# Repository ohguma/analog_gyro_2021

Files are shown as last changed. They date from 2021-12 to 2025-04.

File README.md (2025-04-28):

# アナログ出力ジャイロセンサ

+ 電源が5Vのマイコンキットなどのアナログ入力で利用するためのジャイロセンサ。
+ Arduino 互換機として作成。

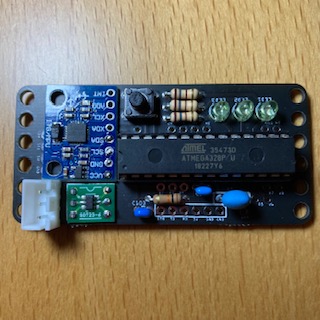
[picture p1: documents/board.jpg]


## スケッチについて

+ こちらで紹介されている「センサーから値を取得するプログラム」と「センサーのキャリブレーションについて」のスケッチ（※1）をまとめて、スイッチの長押しロジックとDAC出力機能を追加して作成。
  + [センサーの使い方(ジャイロ編) : Revolution_Include](http://blog.livedoor.jp/revolution_include/archives/2815979.html)
+ 事前にgithubの「jrowberg/i2cdevlib」をダウンロードしておく。
  + https://github.com/jrowberg/i2cdevlib
  + 「code」ボタンの「Download ZIP」からダウンロードする。
  + 「i2cdevlib-master.zip」を展開し、「Arduino」フォルダ内にある「I2Cdev」「MPU6050」の2フォルダを「Arduino IDE」のライブラリフォルダ内にコピーする。
  + Arduino IDEを再起動し、メニューの「スケッチ」→「ライブラリのインクルード」に「I2Cdev」「MPU6050」があることを確認する。
+ ※1の2つのスケッチではどちらもMPU6050というデータ型が利用されているが、 「MPU6050_6Axis_MotionApps20.h」と「MPU6050.h」をそのまま同時にインクルードするとデータ型「MPU6050」の2重定義でコンパイルがエラーになるので、「#define I2CDEVLIB_MPU6050_TYPEDEF」を事前に記述して「MPU6050.h」でのデータ型「MPU6050」の定義を回避しつつ、自作スケッチではデータ型「MPU6050」でなく、それぞれのヘッダーファイルで定義されている元の形「MPU6050_6Axis_MotionApps20」「MPU6050_Base」を利用した。
+ 起動時の方向を基準として動作する。基準向きの場合に2.5Vを出力し、それより右に向くと電圧が下がり（最小0V）、左に向くと電圧が上がる（最大5V）。基準向きの反対方向で0Vと5Vが入れ替わる。
+ 基準向きから+-1度の範囲内で中央のLEDが点灯する。基準向きから+-5度の範囲内で左右のLEDが点灯する。それ以外の向きはLEDは消灯する。
+ タクトスイッチを短押しした時の方向を基準方向としてリセットする。3秒以上長押しするとキャリブレーションを開始する。キャリブレーション時はセンサーは静止した状態にしておき、LEDが3つとも点灯したらスイッチを離し、キャリブレーションの終了を待つ（数十秒）。 
+ キャリブレーション時に取得したジャイロセンサのオフセット値はEEPROMに保存する。起動時にはEEPROMからオフセット値を読み込んで動作するため、最初にスケッチをアップロードした際にはすぐにキャリブレーションする。

## パーツリスト
個数は明記なければ1個。
+ [Ａｒｄｕｉｎｏ　Ｂｏｏｔｌｏａｄｅｒ書込済（５Ｖ　１６ＭＨｚ仕様）　ＡＴｍｅｇａ３２８Ｐ](https://akizukidenshi.com/catalog/g/gI-12774/)
  + 自前でブートローダーが書き込めるなら「 [ＡＶＲマイコン　ＡＴＭＥＧＡ３２８Ｐ－ＰＵ](https://akizukidenshi.com/catalog/g/gI-03142/)」もあり。
+ MPU6050
  + amazon などでMPU6050(GY-521)として売られているもの。数百円。 
+ [ＭＣＰ４７２６搭載１２ビットＤ／Ａ変換モジュール](https://akizukidenshi.com/catalog/g/gK-07995/)
  + 本センサは水平に設置する前提でヨー軸角度をアナログ出力するのでそのためのDAC。
+ [セラミック発振子（セラロック）コンデンサー内蔵タイプ　１６ＭＨｚ](https://akizukidenshi.com/catalog/g/gP-09576/)
+ 28ピン　ICソケット
+ タクトスイッチ
+ 3mmLED 3個
+ LED用電流制限抵抗 3個（150～1KΩ程度）
+ 328Pリセット回路用の抵抗10KΩ、セラミックコンデンサ 0.01μF(10nF) 103
+ セラミックコンデンサ 0.1μF(100nF) 104　328P用パスコン
+ 配線用のコネクタなど

## 基板・回路図

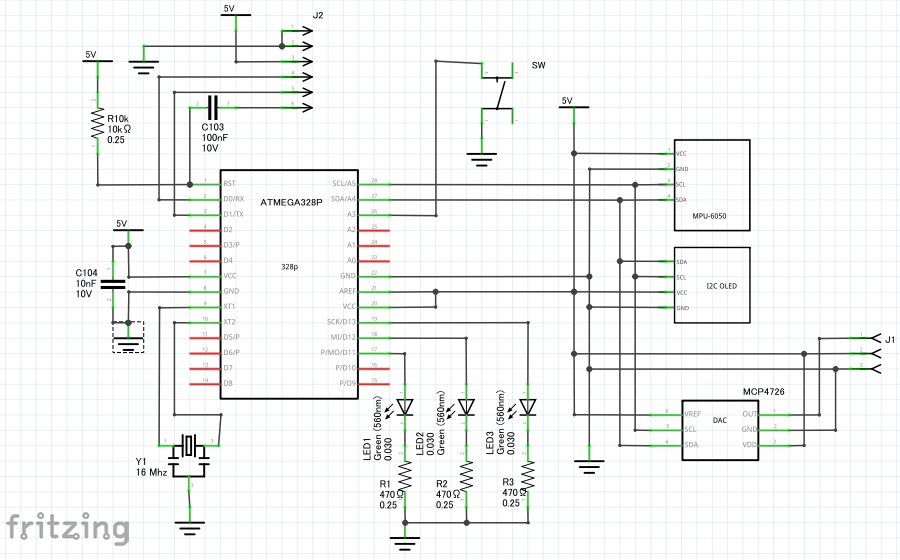
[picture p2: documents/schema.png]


+ OLEDはコストカットのため未実装。なお、I2C接続で画素数128x32のものを直接基板に取り付けできる予定だったが、MPU6050の基板が邪魔になっている。
+ [Fritzing](https://fritzing.org/)で設計し、基板作成まで行った。
+ 基板作成の面付けについては 「[Fritzing入門実習テキスト「Fritzing Basics」#マッハ新書 （ダウンロード商品）](https://booth.pm/ja/items/1414214)」の手順に従った。
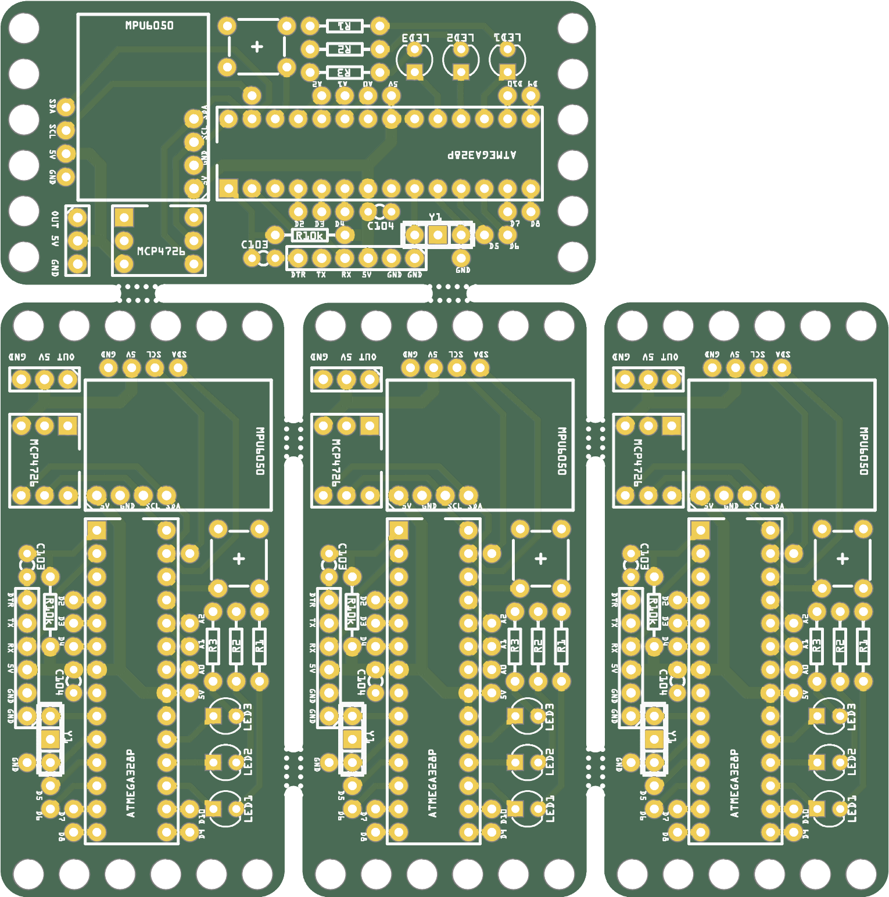
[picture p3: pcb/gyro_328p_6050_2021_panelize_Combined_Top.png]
  + 
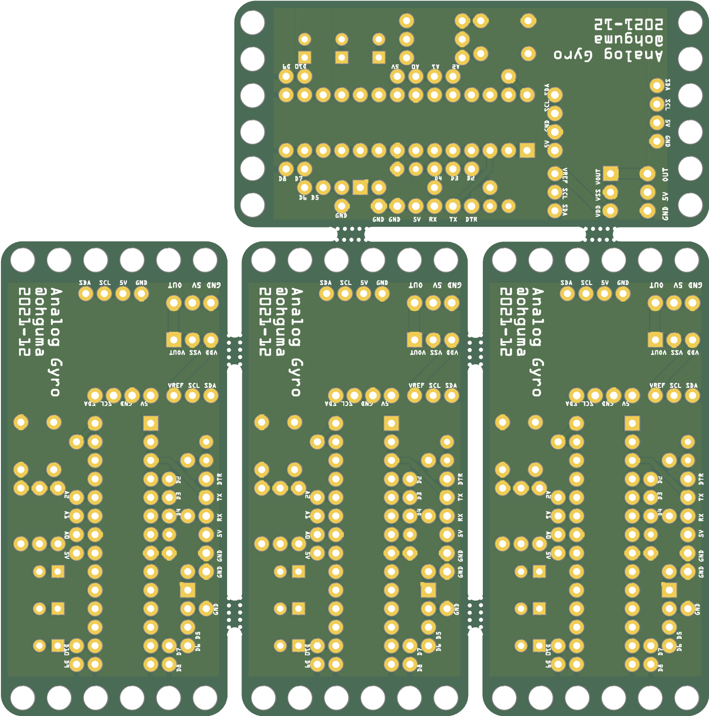
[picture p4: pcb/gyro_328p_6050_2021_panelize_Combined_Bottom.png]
  + 
+ 基板作成は「[JLCPCB](https://jlcpcb.com/)」。つや消し黒が安い。発注から1週間ほどで到着（運送便はUPS、支払いはpaypal）。
  + twitter https://twitter.com/JLCPCB_Japan
+ [発注時ガーバーファイル](./pcb/combined.zip)
+ [GerberPanelizer.exeデータ](./pcb/gyro_328p_6050_2021_panelize.gerberset)
+ [Frizingのプリント基板外形SVG](./pcb/gyro_328p_6050_2021.svg)

+ [KiCAD8データ](./pcb/analog_gyro_2021.zip)

----
2021-12-29 ohguma

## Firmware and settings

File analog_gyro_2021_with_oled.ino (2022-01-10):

/**
  Analog出力ジャイロ with OLED
  2021-12-29 by ohguma

  ▼パーツ
  DAC          MCP4726 秋月
  ジャイロセンサ MPU6050 Amazonなど

  ▼ピン設定
  入力
  　基準向きリセットSW   A3
  出力
  　向き表示LED1,2,3    D11,D12,D13

  ▼参考
  センサーの使い方(ジャイロ編)
  http://blog.livedoor.jp/revolution_include/archives/2815979.html
*/

//#define DEBUG

#ifdef DEBUG
#define DEBUG_PRINTLN(x) Serial.println(x)
#define DEBUG_PRINT(x) Serial.print(x)
#else
#define DEBUG_PRINTLN(x)
#define DEBUG_PRINT(x)
#endif

#include <EEPROM.h>
#include <Wire.h>
#include <I2Cdev.h>
//MP6050の重複をさける
#define I2CDEVLIB_MPU6050_TYPEDEF
#include <MPU6050.h>
#include <MPU6050_6Axis_MotionApps20.h>

//DACアドレス
#define MCP4726_ADDR 0x60

//OLED
//Adafruit_SSD1306の例「ssd1306_128x32_i2c」を流用
#include <SPI.h>
#include <Adafruit_GFX.h>
#include <Adafruit_SSD1306.h>
#define SCREEN_WIDTH 128 // OLED display width, in pixels
#define SCREEN_HEIGHT 32 // OLED display height, in pixels
// Declaration for an SSD1306 display connected to I2C (SDA, SCL pins)
#define OLED_RESET     4 // Reset pin # (or -1 if sharing Arduino reset pin)
Adafruit_SSD1306 display(SCREEN_WIDTH, SCREEN_HEIGHT, &Wire, OLED_RESET);
int c = 0;

//PIN設定
#define LED_RIGHT 13
#define LED_CENTER 12
#define LED_LEFT 11
#define PIN_SW A3
////PIN設定（旧基盤）
//#define LED_RIGHT 11
//#define LED_CENTER 10
//#define LED_LEFT 9
//#define PIN_SW 12

//方向リセットを始めるスイッチ長押し時間[ms]
#define MS_RESET 50
//キャリブレーションを始めるスイッチ長押し時間[ms]
#define MS_CALIB 3000

//キャリブレーション時のオフセット値を保存するEEPROMアドレス
#define POS_GYRO_X  0x00
#define POS_GYRO_Y  0x02
#define POS_GYRO_Z  0x04
#define POS_ACCEL_Z 0x06

//長押し用タイマー変数。押された瞬間のmillis()を保存する
unsigned long tm_reset = 0;
unsigned long tm_calib = 0;

//DAC出力するローカル角度
int16_t mydeg = 0;
//ジャイロセンサ角度とローカル角度のオフセット
int16_t myinitdeg = 0;

//ジャイロセンサ角度計算用
MPU6050_6Axis_MotionApps20 mpu;
int16_t gyro = 0;             //ジャイロセンサ角度
static uint8_t mpuIntStatus;
static bool dmpReady = false; // set true if DMP init was successful
static uint16_t packetSize;   // expected DMP packet size (default is 42 bytes)
uint16_t fifoCount;
uint8_t fifoBuffer[64]; // FIFO storage buffer                 // orientation/motion vars
Quaternion q;           // [w, x, y, z]         quaternion container
VectorFloat gravity;    // [x, y, z]            gravity vector
float ypr[3];           // [yaw, pitch, roll]   yaw/pitch/roll container and gravity vector

void setup()
{
  Serial.begin(9600);
  DEBUG_PRINTLN("Analog Gyro 2021-12");
  DEBUG_PRINTLN("Initialize...");
  //OLED
  if (!display.begin(SSD1306_SWITCHCAPVCC, 0x3C)) { // Address 0x3C for 128x32
    Serial.println(F("SSD1306 FAILED"));
    for (;;); // Don't proceed, loop forever
  }
  delay(1000);
  display.clearDisplay();
  display.setTextColor(WHITE);
  display.setTextSize(2);
  display.setCursor(0, 0);
  display.println(F("AnalogGyro"));
  display.setTextSize(1);
  display.setCursor(0, 16);
  display.println(F("2021-12 ohguma"));
  display.display();
  //ピン設定
  pinMode(LED_RIGHT, OUTPUT);
  pinMode(LED_CENTER, OUTPUT);
  pinMode(LED_LEFT, OUTPUT);
  pinMode(PIN_SW, INPUT_PULLUP);
  //出力初期化
  digitalWrite(LED_RIGHT, LOW);
  digitalWrite(LED_CENTER, LOW);
  digitalWrite(LED_LEFT, LOW);
  //ジャイロセンサ初期化
  init_gyro();
  attach_offset();
  DEBUG_PRINTLN("Start...");
}

void loop()
{
  if (digitalRead(PIN_SW) == HIGH) {
    //キーが押されていないデフォルト状態
    tm_reset = 0;
    tm_calib = 0;
    //ジャイロ値更新
    set_gyro_value();
    //ローカル角度に変換（-180< x <= 180）
    mydeg = gyro - myinitdeg;
    if (mydeg < -180) {
      mydeg += 360;
    } else if (mydeg > 180) {
      mydeg -= 360;
    }
    DEBUG_PRINTLN(mydeg);
    //DAC出力 -180～180のデータを0～4095(2^12-1)のデータに換算する
    int val = constrain(map(mydeg, -180, 180, 4095, 0), 0, 4095);
    Wire.beginTransmission(MCP4726_ADDR);
    Wire.write((uint8_t) ((val >> 8) & 0x0F));   // MSB: (D11, D10, D9, D8)
    Wire.write((uint8_t) (val));  // LSB: (D7, D6, D5, D4, D3, D2, D1, D0)
    Wire.endTransmission();
    //状態LED出力
    if (mydeg >= -5 && mydeg < -1 ) {
      digitalWrite(LED_LEFT, HIGH);
    } else {
      digitalWrite(LED_LEFT, LOW);
    }
    if (mydeg >= -1 && mydeg <= 1 ) {
      digitalWrite(LED_CENTER, HIGH);
    } else {
      digitalWrite(LED_CENTER, LOW);
    }
    if (mydeg > 1 && mydeg <= 5 ) {
      digitalWrite(LED_RIGHT, HIGH);
    } else {
      digitalWrite(LED_RIGHT, LOW);
    }
    if (c % 10 == 0) {
      draw_triangle(mydeg);
    }
    c++;
  } else if (tm_reset == 0 && tm_calib == 0) {
    //スイッチ押し時間計測開始
    tm_reset = millis();
    tm_calib = millis();
  } else if (tm_reset > 0 && millis() - tm_reset > MS_RESET) {
    //ローカル角度のリセット（現時点の向きを基準向きとする）
    tm_reset = 0;
    attach_offset();

  } else if (tm_calib > 0 && millis() - tm_calib > MS_CALIB) {
    //キャリブレーション開始
    tm_calib = 0;
    digitalWrite(LED_RIGHT, HIGH);
    digitalWrite(LED_CENTER, HIGH);
    digitalWrite(LED_LEFT, HIGH);
    action_calibration();
    digitalWrite(LED_RIGHT, LOW);
    digitalWrite(LED_CENTER, LOW);
    digitalWrite(LED_LEFT, LOW);
    init_gyro();
    attach_offset();
  }
}

//ローカル角度のリセット用のオフセット更新
void attach_offset()
{
  myinitdeg = gyro;
}

//ジャイロセンサ値の更新
void set_gyro_value()
{
  mpuIntStatus = false;
  mpuIntStatus = mpu.getIntStatus();
  fifoCount = mpu.getFIFOCount();
  if ((mpuIntStatus & 0x10) || fifoCount == 1024) {
    mpu.resetFIFO();
  } else if (mpuIntStatus & 0x02) {
    while (fifoCount < packetSize) {
      fifoCount = mpu.getFIFOCount();
    }
    mpu.getFIFOBytes(fifoBuffer, packetSize);
    fifoCount -= packetSize;
    mpu.dmpGetQuaternion(&q, fifoBuffer);
    mpu.dmpGetGravity(&gravity, &q);
    mpu.dmpGetYawPitchRoll(ypr, &q, &gravity);
    gyro = degrees(ypr[0]) + 180;
    if (gyro < 0) {
      gyro += 360;
    }
    if (gyro > 359) {
      gyro -= 360;
    }
  }
}

//ジャイロセンサ初期化
void init_gyro()
{
  int val;
  mpu.initialize();
  while (!mpu.testConnection()) {
  }
  if (mpu.testConnection() != true) {
    DEBUG_PRINTLN("MPU disconection");
    while (true) {}
  }
  if (mpu.dmpInitialize() != 0) {
    DEBUG_PRINTLN("MPU break");
    while (true) {}
  }
  EEPROM.get(POS_GYRO_X, val);
  mpu.setXGyroOffset(val);
  EEPROM.get(POS_GYRO_Y, val);
  mpu.setYGyroOffset(val);
  EEPROM.get(POS_GYRO_Z, val);
  mpu.setZGyroOffset(val);
  EEPROM.get(POS_ACCEL_Z, val);
  mpu.setZAccelOffset(val);
  mpu.setDMPEnabled(true);
  mpuIntStatus = mpu.getIntStatus();
  dmpReady = true;
  packetSize = mpu.dmpGetFIFOPacketSize();
  //少し待つ
  for (int i = 0; i < 100; i++) {
    set_gyro_value();
  }
}


// 以下は長押し時のキャリブレーション用
MPU6050_Base accelgyro;
int state = 0;
int16_t ax, ay, az, gx, gy, gz;
int mean_ax, mean_ay, mean_az, mean_gx, mean_gy, mean_gz;
int ax_offset, ay_offset, az_offset, gx_offset, gy_offset, gz_offset;
int buffersize = 1000;   //Amount of readings used to average, make it higher to get more precision but sketch will be slower  (default:1000)
int acel_deadzone = 8;   //Acelerometer error allowed, make it lower to get more precision, but sketch may not converge  (default:8)
int giro_deadzone = 1;   //Giro error allowed, make it lower to get more precision, but sketch may not converge  (default:1)

//キャリブレーション処理
void action_calibration()
{
  display.clearDisplay();
  display.setTextColor(WHITE);
  display.setTextSize(1);
  display.setCursor(0, 0);
  display.println(F("Calibrationing..."));
  display.display();
  DEBUG_PRINTLN("\nMPU6050 Calibration");
  //delay(2000);
  DEBUG_PRINTLN("\nYour MPU6050 should be placed in horizontal position, with package letters facing up. \nDon't touch it until you see a finish message.\n");
  //delay(3000);
  // verify connection
  DEBUG_PRINTLN(accelgyro.testConnection() ? "MPU6050 connection successful" : "MPU6050 connection failed");
  delay(1000);
  // reset offsets
  accelgyro.setXAccelOffset(0);
  accelgyro.setYAccelOffset(0);
  accelgyro.setZAccelOffset(0);
  accelgyro.setXGyroOffset(0);
  accelgyro.setYGyroOffset(0);
  accelgyro.setZGyroOffset(0);
  Wire.begin();
  TWBR = 24; // 400kHz I2C clock (200kHz if CPU is 8MHz). Leonardo measured 250kHz.
  accelgyro.initialize();
  while (1) {
    if (state == 0) {
      DEBUG_PRINTLN("\nReading sensors for first time...");
      meansensors();
      state++;
      delay(1000);
    }
    if (state == 1) {
      DEBUG_PRINTLN("\nCalculating offsets...");
      calibration();
      state++;
      delay(1000);
    }
    if (state == 2) {
      meansensors();
      DEBUG_PRINTLN("\nFINISHED!");
      DEBUG_PRINT("\nSensor readings with offsets:\t");
      DEBUG_PRINT(mean_ax);
      DEBUG_PRINT("\t");
      DEBUG_PRINT(mean_ay);
      DEBUG_PRINT("\t");
      DEBUG_PRINT(mean_az);
      DEBUG_PRINT("\t");
      DEBUG_PRINT(mean_gx);
      DEBUG_PRINT("\t");
      DEBUG_PRINT(mean_gy);
      DEBUG_PRINT("\t");
      DEBUG_PRINTLN(mean_gz);
      DEBUG_PRINT("Your offsets:\t");
      DEBUG_PRINT(ax_offset);
      DEBUG_PRINT("\t");
      DEBUG_PRINT(ay_offset);
      DEBUG_PRINT("\t");
      DEBUG_PRINT(az_offset);
      DEBUG_PRINT("\t");
      DEBUG_PRINT(gx_offset);
      DEBUG_PRINT("\t");
      DEBUG_PRINT(gy_offset);
      DEBUG_PRINT("\t");
      DEBUG_PRINTLN(gz_offset);
      DEBUG_PRINTLN("\nData is printed as: acelX acelY acelZ giroX giroY giroZ");
      EEPROM.put(POS_GYRO_X, gx_offset);
      EEPROM.put(POS_GYRO_Y, gy_offset);
      EEPROM.put(POS_GYRO_Z, gz_offset);
      EEPROM.put(POS_ACCEL_Z, az_offset);
      return;
    }
  }
}

void meansensors()
{
  long i = 0;
  long buff_ax = 0, buff_ay = 0, buff_az = 0;
  long buff_gx = 0, buff_gy = 0, buff_gz = 0;
  int x = -1, x2 = -1;
  display.fillRect(0, 10, display.width(), display.height(), SSD1306_BLACK);
  display.display();
  display.setCursor(0, 10);
  display.println(F("meansensors"));
  display.display();
  while (i < (buffersize + 101)) {
    // read raw accel/gyro measurements from device
    accelgyro.getMotion6(&ax, &ay, &az, &gx, &gy, &gz);
    if (i > 100 && i <= (buffersize + 100)) { //First 100 measures are discarded
      buff_ax = buff_ax + ax;
      buff_ay = buff_ay + ay;
      buff_az = buff_az + az;
      buff_gx = buff_gx + gx;
      buff_gy = buff_gy + gy;
      buff_gz = buff_gz + gz;
    }
    if (i == (buffersize + 100)) {
      mean_ax = buff_ax / buffersize;
      mean_ay = buff_ay / buffersize;
      mean_az = buff_az / buffersize;
      mean_gx = buff_gx / buffersize;
      mean_gy = buff_gy / buffersize;
      mean_gz = buff_gz / buffersize;
    }
    i++;
    delay(2); //Needed so we don't get repeated measures
    x = map(i, 0, buffersize + 100, 0, 127);
    if (x != x2) {
      display.drawLine(x, 20, x, 29, WHITE);
      display.display();
      x2 = x;
    }
  }
}

void calibration()
{
  ax_offset = -mean_ax / 8;
  ay_offset = -mean_ay / 8;
  az_offset = (16384 - mean_az) / 8;
  gx_offset = -mean_gx / 4;
  gy_offset = -mean_gy / 4;
  gz_offset = -mean_gz / 4;
  display.fillRect(0, 10, display.width(), display.height(), SSD1306_BLACK);
  display.display();
  display.setCursor(0, 10);
  display.println(F("calibration"));
  display.setCursor(0, 20);
  display.println(F("- - - - - -"));
  display.display();
  while (1) {
    int ready = 0;
    int before_ready = -1;
    accelgyro.setXAccelOffset(ax_offset);
    accelgyro.setYAccelOffset(ay_offset);
    accelgyro.setZAccelOffset(az_offset);
    accelgyro.setXGyroOffset(gx_offset);
    accelgyro.setYGyroOffset(gy_offset);
    accelgyro.setZGyroOffset(gz_offset);
    meansensors();
    DEBUG_PRINTLN("...");
    if (abs(mean_ax) <= acel_deadzone) {
      ready++;
    } else {
      ax_offset = ax_offset - mean_ax / acel_deadzone;
    }
    if (abs(mean_ay) <= acel_deadzone) {
      ready++;
    } else {
      ay_offset = ay_offset - mean_ay / acel_deadzone;
    }
    if (abs(16384 - mean_az) <= acel_deadzone) {
      ready++;
    } else {
      az_offset = az_offset + (16384 - mean_az) / acel_deadzone;
    }
    if (abs(mean_gx) <= giro_deadzone) {
      ready++;
    } else {
      gx_offset = gx_offset - mean_gx / (giro_deadzone + 1);
    }
    if (abs(mean_gy) <= giro_deadzone) {
      ready++;
    } else {
      gy_offset = gy_offset - mean_gy / (giro_deadzone + 1);
    }
    if (abs(mean_gz) <= giro_deadzone) {
      ready++;
    } else {
      gz_offset = gz_offset - mean_gz / (giro_deadzone + 1);
    }
    if (before_ready != ready) {
      display.setCursor(0, 20);
      if (ready == 1) {
        display.println(F("O - - - - -"));
      } else if (ready == 2) {
        display.println(F("O O - - - -"));
      } else if (ready == 3) {
        display.println(F("O O O - - -"));
      } else if (ready == 4) {
        display.println(F("O O O O - -"));
      } else if (ready == 5) {
        display.println(F("O O O O O -"));
      } else if (ready == 6) {
        display.println(F("O O O O O O"));
      }
      display.display();
    }
    if (ready == 6) {
      break;
    }
  }
}

//OLEDに三角描画
void draw_triangle(int16_t deg)
{
  char s[6];
  display.clearDisplay();
  display.setTextSize(3);
  display.setTextColor(WHITE);
  display.setCursor(48, 0);
  if (deg >= 0) {
    display.print(F(" "));
  }
  if (abs(deg) < 100) {
    display.print(F(" "));
  }
  if (abs(deg) < 10) {
    display.print(F(" "));
  }
  display.println(deg);

  int x1_, y1_, x2_, y2_, x3_, y3_;
  float x1, y1, x2, y2, x3, y3;
  float sn, cs;
  sn = sin(- 3.14 * (deg + 180) / 180);
  cs = cos(- 3.14 * (deg + 180) / 180);
  x1 = 0;
  y1 = 15;
  x2 = -4;
  y2 = -15;
  x3 = 4;
  y3 = -15;
  x1_ = (int)(x1 * cs - y1 * sn) + 16;
  y1_ = (int)(x1 * sn + y1 * cs) + 16;
  x2_ = (int)(x2 * cs - y2 * sn) + 16;
  y2_ = (int)(x2 * sn + y2 * cs) + 16;
  x3_ = (int)(x3 * cs - y3 * sn) + 16;
  y3_ = (int)(x3 * sn + y3 * cs) + 16;
  display.drawLine(x1_, y1_, x2_, y2_, WHITE);
  display.drawLine(x2_, y2_, x3_, y3_, WHITE);
  display.drawLine(x3_, y3_, x1_, y1_, WHITE);
  display.display();
}

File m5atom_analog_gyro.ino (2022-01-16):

/**
  M5Atom Matrix Analog出力ジャイロ

  Grove G26 DAC でジャイロセンサによる方位をアナログ出力
  
  参考
  Arduinoで信号処理をする上で便利なフィルタのライブラリ
  https://ehbtj.com/electronics/filter-library-useful-for-arduino-signal-processing/#Madgwick

*/

#include "M5Atom.h"
#include <MadgwickAHRS.h>   // 角度と角速度にMadgwickフィルタをかけるライブラリ
Madgwick MadgwickFilter;

#include "EEPROM.h"
//キャリブレーション時のオフセット値を保存するEEPROMアドレス
#define POS_ACCEL_X 0x00
#define POS_ACCEL_Y 0x04
#define POS_ACCEL_Z 0x08
#define POS_GYRO_X  0x0C
#define POS_GYRO_Y  0x10
#define POS_GYRO_Z  0x14

//LEDの方向表示
// 0  1  2  3  4
// 5  6  7  8  9
// 10 11 12 13 14
// 15 16 17 18 19
// 20 21 22 23 24 ↓コネクタ側
#define NUM_CLOCK 12
uint8_t clockwise[NUM_CLOCK] = {2, 3, 9, 14, 19, 23, 22, 21, 15, 10, 5, 1};
uint8_t pos_time = 0;
uint8_t pos_time_before = 13;

#define PIN_DAC 26

float pitch = 0.0F;
float roll  = 0.0F;
float yaw   = 0.0F;
float accX = 0, accY = 0, accZ = 0;
float gyroX = 0 , gyroY = 0 , gyroZ = 0;
float accX_offset = 0, accY_offset = 0, accZ_offset = 0;
float gyroX_offset = 0 , gyroY_offset = 0 , gyroZ_offset = 0;
float yaw_offset  = 0.0F;
float yaw_current = 0.0F;

void setup() {
  //M5Stackシリーズ M5.begin()の互換性
  //https://qiita.com/penguinprogrammer/items/5abf3e4f9583e41e9cfa
  //M5Atom : SerialEnable, I2CEnable, DisplayEnable
  M5.begin(true, true, true);
  M5.IMU.Init();
  M5.IMU.SetGyroFsr(M5.IMU.GFS_250DPS); //250,,500,1000,2000
  M5.IMU.SetAccelFsr(M5.IMU.AFS_2G); //2,4,8,16

  if (!EEPROM.begin(24)) {  //②
    Serial.println("Failed to initialise EEPROM");
    Serial.println("Restarting...");
    delay(1000);
    ESP.restart();
  }
  accX_offset = EEPROM.readFloat(POS_ACCEL_X);
  accY_offset = EEPROM.readFloat(POS_ACCEL_Y);
  accZ_offset = EEPROM.readFloat(POS_ACCEL_Z);
  gyroX_offset = EEPROM.readFloat(POS_GYRO_X);
  gyroY_offset = EEPROM.readFloat(POS_GYRO_Y);
  gyroZ_offset = EEPROM.readFloat(POS_GYRO_Z);

  MadgwickFilter.begin(100);  // Madgwickフィルタの周波数を100Hzに設定。

  attach_offset();
}

void loop() {
  M5.IMU.getGyroData(&gyroX, &gyroY, &gyroZ);
  M5.IMU.getAccelData(&accX, &accY, &accZ);
  MadgwickFilter.updateIMU(gyroX - gyroX_offset, gyroY - gyroY_offset, gyroZ - gyroZ_offset, accX - accX_offset, accY - accY_offset, accZ - accZ_offset);
  pitch  = MadgwickFilter.getPitch();
  roll  = MadgwickFilter.getRoll();
  yaw  = MadgwickFilter.getYaw();
  //  M5.IMU.getAhrsData(&pitch, &roll, &yaw);
  if (M5.Btn.wasPressed()) {
    dacWrite(PIN_DAC, 128);
    M5.dis.drawpix(12, 0x0000ff); //BLUE
    delay(1000);
    M5.dis.drawpix(12, 0x000000);
    if (M5.Btn.read()) { //キーが押されたままだったら長押しと判定
      action_calibration();
    }
    attach_offset();
  }
  //データ出力（0 <= yaw <  360　小←　→大)
  //過去のAnalog gyroに合わせて、大←　→小とする。
  yaw_current = -(yaw - yaw_offset);  // -360 < x < 360
  if (yaw_current < -180.0F) {
    yaw_current += 360.0F;
  } else if (yaw_current > 180.0F) {
    yaw_current -= 360.0F;
  }

  int dacout = map((int)yaw_current, -180, 180, 0, 255);
  dacout = constrain(dacout, 0, 255);
  dacWrite(PIN_DAC, dacout);

  //LED表示
  float oneclock = 360.0 / NUM_CLOCK;
  pos_time = (int)((yaw_current + 360.0 + oneclock / 2.0) / oneclock) % NUM_CLOCK;
  if (pos_time_before != pos_time) {
    M5.dis.drawpix(clockwise[pos_time_before], 0x000000);
    M5.dis.drawpix(clockwise[pos_time], 0x400000); //RED
    pos_time_before = pos_time;
  }
  if (yaw_current < -1.0 && yaw_current >= -5.0) {
    M5.dis.drawpix(6, 0x004000); //GREEN
  } else {
    M5.dis.drawpix(6, 0x000000);
  }
  if (abs(yaw_current) <= 1.0) {
    M5.dis.drawpix(7, 0x004000); //GREEN
  } else {
    M5.dis.drawpix(7, 0x000000);
  }
  if (yaw_current > 1.0 && yaw_current <= 5.0) {
    M5.dis.drawpix(8, 0x004000); //GREEN
  } else {
    M5.dis.drawpix(8, 0x000000);
  }

  Serial.printf("%d %5.2f %5.2f ", pos_time, yaw_current, yaw);
  Serial.printf("%5.2f %5.2f %5.2f ", gyroX, gyroY, gyroZ );
  Serial.printf("%5.2f %5.2f %5.2f\n", accX, accY, accZ );
  delay(10);
  M5.update();
}

void attach_offset()
{
  Serial.printf("\n[attach_offset]");
  M5.IMU.getGyroData(&gyroX, &gyroY, &gyroZ);
  M5.IMU.getAccelData(&accX, &accY, &accZ);
  MadgwickFilter.updateIMU(gyroX - gyroX_offset, gyroY - gyroY_offset, gyroZ - gyroZ_offset, accX - accX_offset, accY - accY_offset, accZ - accZ_offset);
  yaw_offset  = MadgwickFilter.getYaw();

  if (isnan(yaw_offset)) {
    action_calibration();
  }
}


float mean_ax, mean_ay, mean_az, mean_gx, mean_gy, mean_gz;
float ax_offset, ay_offset, az_offset, gx_offset, gy_offset, gz_offset;
int buffersize = 1000;   //平均化時の読み取り回数。大きくすると制度が上がるが、速度低下する。
float acel_deadzone = 0.02;   //加速度センサのエラー許容範囲。下げすぎると収束しないかも。
float giro_deadzone = 0.01;   //ジャイロセンサのエラー許容範囲。下げすぎると収束しないかも。

void action_calibration()
{
  int state = 0;
  Serial.printf("\n[action_calibration]");
  M5.dis.drawpix(12, 0x808000); //YELLOW
  delay(1000);
  //reset offset
  accX_offset = 0.0;
  accY_offset = 0.0;
  accZ_offset = 0.0;
  gyroX_offset = 0.0;
  gyroY_offset = 0.0;
  gyroZ_offset = 0.0;
  while (1) {
    if (state == 0) {
      Serial.printf("\nReading sensors for first time...");
      meansensors();
      state = 1;
      delay(1000);
    }
    if (state == 1) {
      Serial.printf("\nCalculating offsets...");
      calibration();
      state = 2;
      delay(1000);
    }
    if (state == 2) {
      break;
    }
  }
  Serial.printf("\nFINISHED!");
  Serial.printf("\noffsets : ");
  Serial.printf("AX:%5.2f ", ax_offset);
  Serial.printf("AY:%5.2f ", ay_offset);
  Serial.printf("AZ:%5.2f ", az_offset);
  Serial.printf("GX:%5.2f ", gx_offset);
  Serial.printf("GY:%5.2f ", gy_offset);
  Serial.printf("GZ:%5.2f ", gz_offset);
  accX_offset = ax_offset;
  accY_offset = ay_offset;
  accZ_offset = az_offset;
  gyroX_offset = gx_offset;
  gyroY_offset = gy_offset;
  gyroZ_offset = gz_offset;
  EEPROM.writeFloat(POS_ACCEL_X, accX_offset);
  EEPROM.writeFloat(POS_ACCEL_Y, accY_offset);
  EEPROM.writeFloat(POS_ACCEL_Z, accZ_offset);
  EEPROM.writeFloat(POS_GYRO_X, gyroX_offset);
  EEPROM.writeFloat(POS_GYRO_Y, gyroY_offset);
  EEPROM.writeFloat(POS_GYRO_Z, gyroZ_offset);
  EEPROM.commit();
  delay(3000);
  M5.dis.drawpix(12, 0x000000);
}
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

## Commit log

2021-12-28 Fritzingデータ追加
    [gyro_328p_6050_2021.fzz]
2021-12-28 Arduinoスケッチ追加
2021-12-29 回路図の見栄えを修正
    [gyro_328p_6050_2021.fzz]
2021-12-29 PCB関連データ
2021-12-29 ドキュメント更新
2021-12-29 誤字修正と追記
2021-12-29 パーツ漏れ追記
2021-12-29 OLEDありスケッチ追加
2022-01-10 mpu初期化時の待機処理追加
2022-01-16 M5Atom Matrix版追加
2025-04-28 KiCAD8データ追加
